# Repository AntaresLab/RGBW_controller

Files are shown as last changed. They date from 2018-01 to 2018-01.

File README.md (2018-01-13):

# RGBW_controller
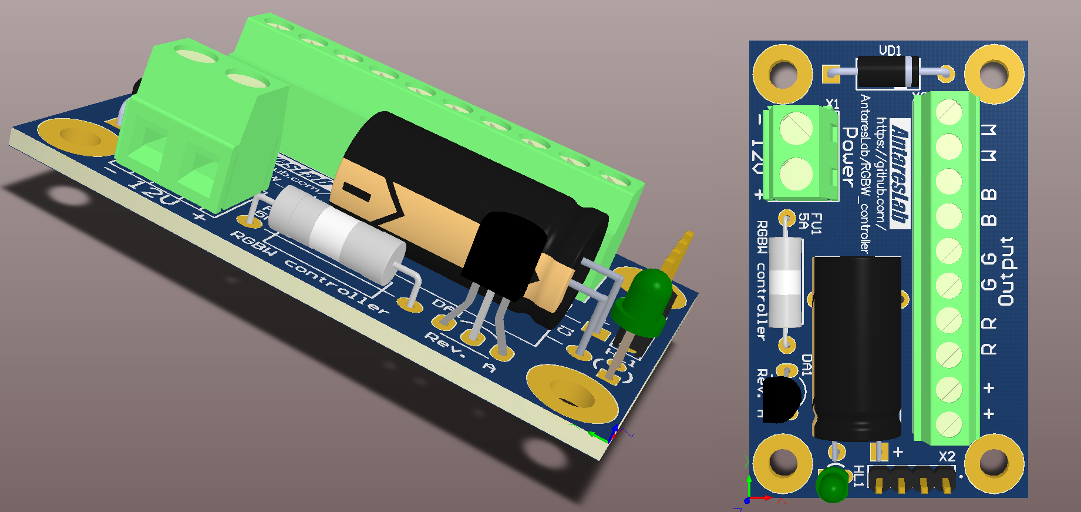
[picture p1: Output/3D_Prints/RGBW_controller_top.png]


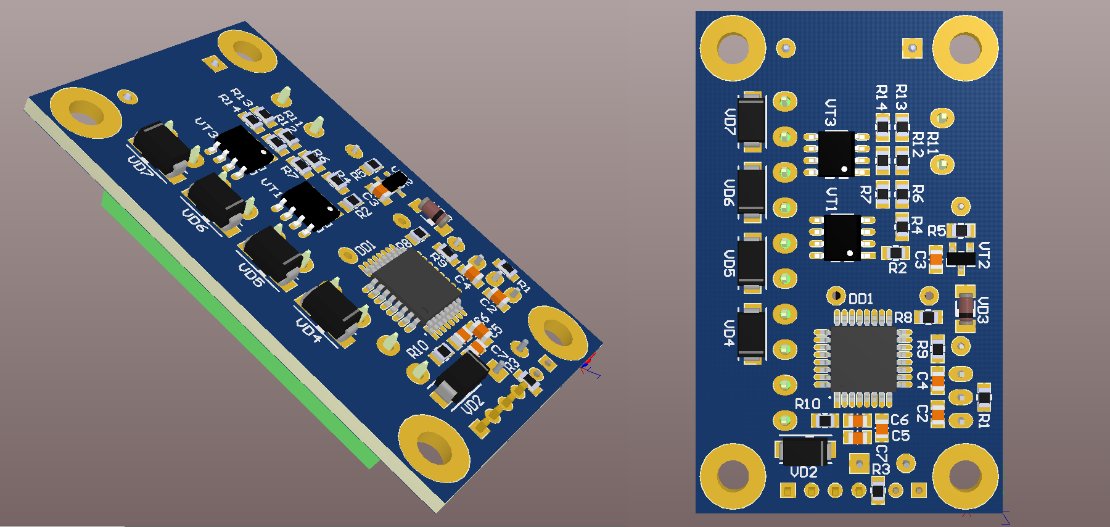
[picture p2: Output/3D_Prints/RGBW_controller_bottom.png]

***
This PCB designed for the LED strips controlling.

It allows to control 4 channnels of LED strips or another similar-controlled loads.

Channels can be paralleled in various combinations within one PCBA to increase the load capacity. In this case you need to ensure compatibility of such connection with your firmware of controlling MCU.

When using the components, specified in the schematic, you can get up to 2A from every channel in normal conditions without strong heating. Operating voltage of this PCBA is 9...15VDC. You will can increase maximal voltage and currents, if use suitable semiconductor devices.

This PCBA is protected against reverse Power polarity and overvoltage.

**Please, use a fuse that matches the total consumption of your loads.**

All output channels are connected to the outputs of the microcontroller timer. Thus, a hardware PWM signal can be generated at all outputs.

Trere is also a power-off detector installed on this PCB. If MCU PE5 pin input is low, power is ok. If you are not satisfied with the threshold of operation of the power-off detector, change the value of the zener diode VD3. If you are not satisfied with the delay in triggering the power-off detector, change the C3 capacitor rating.

Output drivers are connected to PC4 (R), PC3 (G), PC2 (B), PC1 (W) MCU pins.

MCU programms via the SWIM interface (X2).

There is a STM8S105K4 MCU used in this board.

PCB dimensions are 33x54mm. Maximal height of the components above the PCB is 10mm on top side and 2mm (excluding the top side components pins) on bottom side.

Mounting holes are designed for M3 screws. The distances between them are 25x46mm. Distance between the center of the mounting hole and the nearest edge of the board is 4mm.

***
I will be glad to any contribution to the development of my projects.

If you will find any mistakes or inaccuracies in my projects, please notify me about that.

I will be glad, if you modify, impove or port my projects to another CADs. Please notify me if you do this, and I will mention here about that.

If you have a successful experience of using this board with components other than listed in BOM-list, or with the exceeding the declared parameters, please notify me so that I can reflect it here.

If you develop any firmware for this board, please notify me of it, and I will post here a link to your project.

If you develop another version of this board, please notify me of it to document your branch or post a link to your branch here.

***
All schematics and board design files here are Copyright (c) 2018 AntaresLab aka Sergey Starovoitov serega.starovoitov@mail.ru.

Provided under the GNU GPL v3.

***
## Known firmware for this RGBW controller

* [RGB strip-based mood lamp](https://github.com/AntaresLab/Mood_lamp)

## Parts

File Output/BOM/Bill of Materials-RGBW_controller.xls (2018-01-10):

Designator | Part Number | Description | Footprint | Quantity | Digikey Part Number
C1 | UVY1E102MPD | 1000uF 25V electrolytic capacitor | H20D10RM5 | 1 | UVY1E102MPD-ND (https://www.digikey.com/product-detail/en/nichicon/UVY1E102MPD/UVY1E102MPD-ND/2428012)
C2, C3, C4, C5, C7 | CL21B104KBCNNNC | 100nF 50V 0805 SMD capacitor | 0805 | 5 | 1276-1003-1-ND (https://www.digikey.com/product-detail/en/samsung-electro-mechanics/CL21B104KBCNNNC/1276-1003-1-ND/3889089)
C6 | CL21B105KOFNNNG | 1uF 50V 0805 SMD capacitor | 0805 | 1 | 1276-6471-1-ND (https://www.digikey.com/product-detail/en/samsung-electro-mechanics/CL21B105KOFNNNG/1276-6471-1-ND/5958099)
DA1 | LM78L05ACZXA | 5V Positive Linear Voltage Regulator | TO92 | 1 | LM78L05ACZXACT-ND (https://www.digikey.com/product-detail/en/on-semiconductor/LM78L05ACZXA/LM78L05ACZXACT-ND/3042488)
DD1 | STM8S105K4T6CTR | STM8 MCU with 16kB Flash | TQFP32 | 1 | STM8S105K4T6CTR-ND (https://www.digikey.com/product-detail/en/stmicroelectronics/STM8S105K4T6CTR/STM8S105K4T6CTR-ND/2214626)
FU1 | C310T-SC-5-R-TR1 | 5A PCB Leaded Fuse 4x10 | L10D4RM15 | 1 | 283-4691-1-ND (https://www.digikey.com/product-detail/en/eaton/C310T-SC-5-R-TR1/283-4691-1-ND/6189498)
HL1 | 151031VS06000 | 3mm DIP green LED | H10D3RM2,5 | 1 | 732-5008-ND (https://www.digikey.com/product-detail/en/wurth-electronics-inc/151031VS06000/732-5008-ND/4489988)
R1, R5, R8 | RC0805JR-071KL | 1k 0805 SMD resistor | 0805 | 3 | 311-1.0KARCT-ND (https://www.digikey.com/product-detail/en/yageo/RC0805JR-071KL/311-1.0KARCT-ND/731165)
R2, R6, R11, R13 | RC0805JR-0710RP | 10R 0805 SMD resistor | 0805 | 4 | YAG1330CT-ND (https://www.digikey.com/product-detail/en/yageo/RC0805JR-0710RP/YAG1330CT-ND/4935443)
R3 | RC0805JR-072K2L | 2,2k 0805 SMD resistor | 0805 | 1 | 311-2.2KARDKR-ND
R4, R7, R9, R10, R12, R14 | RC0805JR-0710KL | 10k 0805 SMD resistor | 0805 | 6 | 311-10KARCT-ND (https://www.digikey.com/product-detail/en/yageo/RC0805JR-0710KL/311-10KARCT-ND/731188)
VD1 | P6KE18A | 15V 600W THT Unidirectional Supressor | DO15 | 1 | 497-11385-1-ND (https://www.digikey.com/product-detail/en/stmicroelectronics/P6KE18A/497-11385-1-ND/2674540)
VD2 | S1MTR | 1A Surface Mount Rectifier | SMA | 1 | 1655-1506-1-ND (https://www.digikey.com/product-detail/en/smc-diode-solutions/S1MTR/1655-1506-1-ND/6022951)
VD3 | BZV55-C9V1,115 | 9,1V 500mW SMD Zener Diode | SOD80 | 1 | 1727-4978-1-ND (https://www.digikey.com/product-detail/en/nexperia-usa-inc/BZV55-C9V1115/1727-4978-1-ND/2531559)
VD4, VD5, VD6, VD7 | SS34L RVG | 3A Low Case Schottky Barrier Diode | SMA | 4 | SS34L RVGCT-ND (https://www.digikey.com/product-detail/en/taiwan-semiconductor-corporation/SS34L-RVG/SS34L-RVGCT-ND/7359610)
VT1, VT3 | FDS9926A | Dual 20V 6.5A SO8 SMD n-MOSFET transistor with Rds=30mOhm | SO8 | 2 | FDS9926ACT-ND (https://www.digikey.com/product-detail/en/on-semiconductor/FDS9926A/FDS9926ACT-ND/965635)
VT2 | BC817-25LT3G | 45V 500mA SOT23-3 SMD NPN transistor with h21>100 | SOT23-3 | 1 | BC817-25LT3GOSCT-ND (https://www.digikey.com/product-detail/en/on-semiconductor/BC817-25LT3G/BC817-25LT3GOSCT-ND/2704953)
X1 | VI0201550000G | 2 pin Screw Terminal PCB Block | DG301-5,0-2P | 1 | 609-3927-ND (https://www.digikey.com/product-detail/en/amphenol-anytek/VI0201550000G/609-3927-ND/2261273)
X2 | 61300411121 | 4 pin SWIM connector for STM8 MCU programming | PLS4 | 1 | 732-5317-ND (https://www.digikey.com/product-detail/en/wurth-electronics-inc/61300411121/732-5317-ND/4846827)
X3 | YO1021500000G | 10 pin Screw Terminal PCB Block | DG380-3,81-10P | 1 | 609-3926-ND (https://www.digikey.com/product-detail/en/amphenol-anytek/YO1021500000G/609-3926-ND/2261375)

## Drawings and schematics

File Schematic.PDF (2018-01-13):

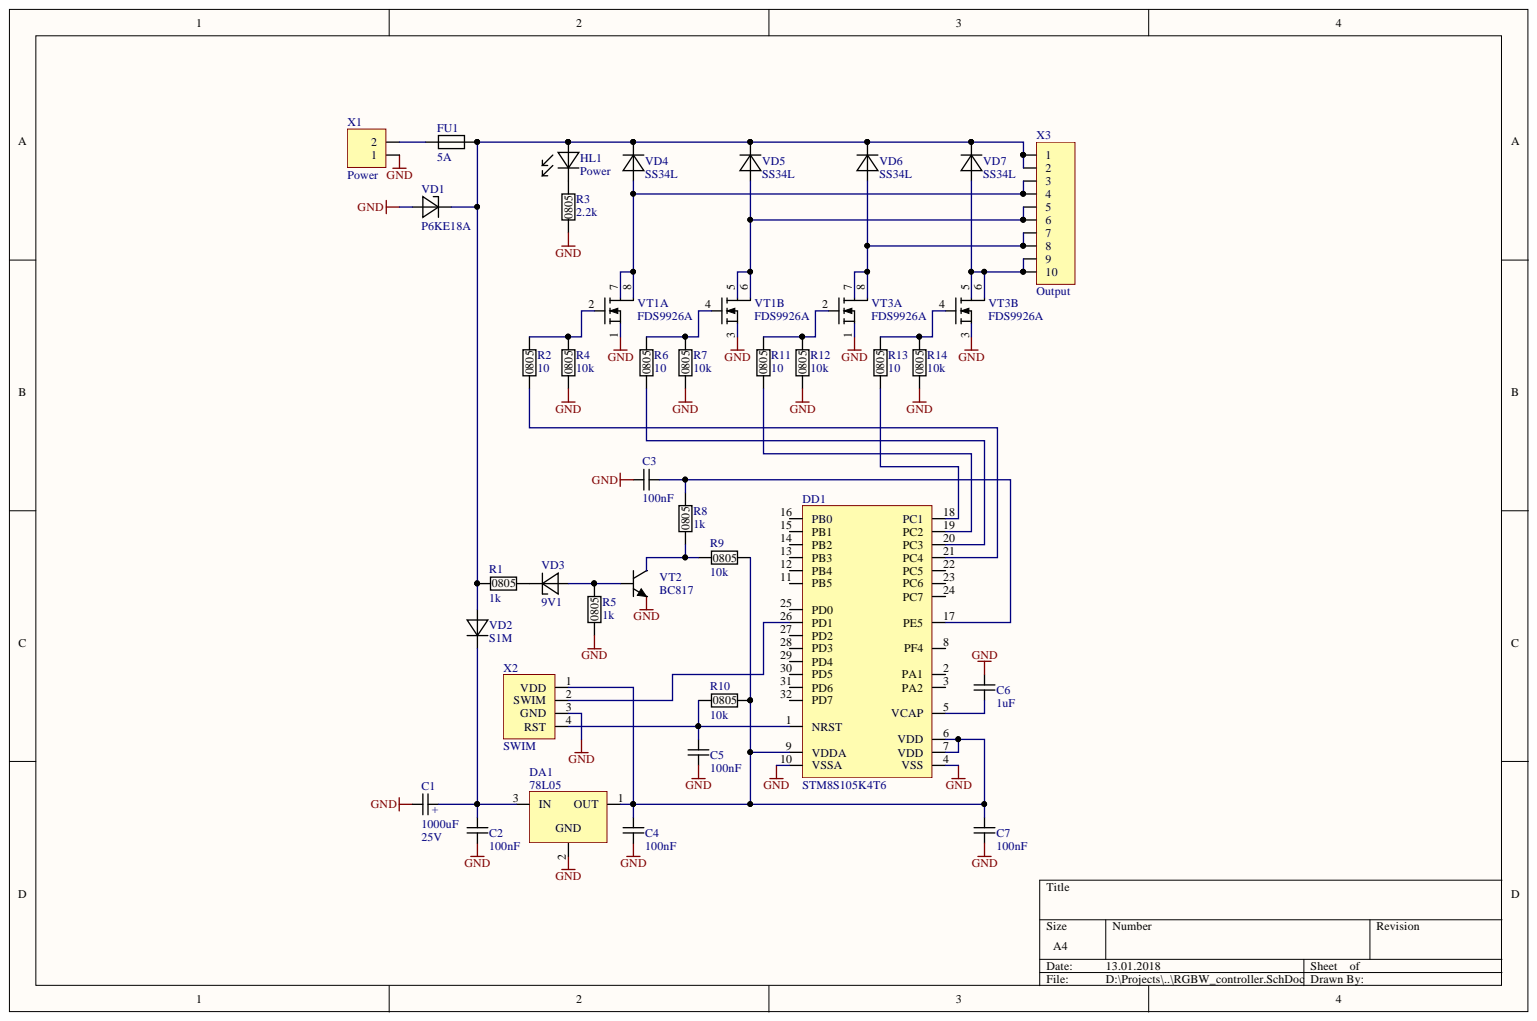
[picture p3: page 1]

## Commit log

2018-01-10 v.1.0.0
    RGBW controller rev.A PCB project initial commit
    [Bill of Materials-RGBW_controller.xls, RGBW_controller.PcbDoc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]
2018-01-10 v.1.0.0
    Folders structure was changed
    [Bill of Materials-RGBW_controller.xls, RGBW_controller.PcbDoc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]
2018-01-10 v.1.0.0
    Files structure changed
    [Bill of Materials-RGBW_controller.xls, RGBW_controller.PcbDoc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]
2018-01-10 V.1.0.0
    3D view image added
    [RGBW_controller.PrjPcb]
2018-01-11 V.1.0.0
    3D Prints folder was renamed to make it visible on project page
2018-01-11 V.1.0.0
    Readme file:
    - paragraphes added
    - PCBA mechanical data added
2018-01-11 V1.0.0
    Top and bottom sides PCB 3D view images added
2018-01-13 V.1.0.1
    File structure was changed
    Power-off detector connection error was fixed
    [Bill of Materials-RGBW_controller.xls, RGBW_controller.PcbDoc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]
2018-01-13 V.1.0.1
    File structure changed
    [Bill of Materials-RGBW_controller.xls, RGBW_controller.PcbDoc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]
2018-01-13 V.1.0.1
    "Rev.B" PCB title added
    [RGBW_controller.PcbDoc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]
